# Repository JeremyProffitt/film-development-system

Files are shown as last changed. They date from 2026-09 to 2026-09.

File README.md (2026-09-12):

# film-development-system

Automating black & white and C-41 film processing around a Paterson Super System 4
tank: how to fill and drain it quickly, how to route the chemistry, and a motorised
tumbler that gives the tank real inversion agitation.

Part of a set of analog darkroom projects alongside
[film-dryer](https://github.com/JeremyProffitt/film-dryer) (filtered air system for film drying boxes)
and [film-holders](https://github.com/JeremyProffitt/film-holders).

## Repository layout

```
research/   analysis and drawing sets for the tank itself
tumbler/    the motorised tank tumbler: parametric model, STLs, drawings
```

Every PDF here is generated by the script beside it. Nothing is hand-drawn, and
every dimension quoted on a tumbler sheet is measured off the exported STL rather
than taken from the design intent.

### research/

| file | what it is |
|---|---|
| `tank_drawing_set.py` / `.pdf` | 6 sheets. The Super System 4 range and a dimensioned drawing of every component of the Multi-Reel 3: tank body, centre column, light-trap funnel, lid, agitator rod. |
| `fill_and_drain_study.py` / `.pdf` | 15 sheets. Why the stock tank fills slowly, every route to filling and draining it faster, tilt geometry, pump vs gravity, fluid architecture, carry-over budget, and per-process sequences for B&W and C-41. |

```bash
cd research && python fill_and_drain_study.py
```

### tumbler/

A drum lying on its side with a bore running through it at right angles. The tank
lives in that bore, so one turn of the drum is one full inversion of the tank.
The first 34 mm at each open end carries square grooves on its **inner** wall;
eight TT motors — four per end, 90° apart — sit inside the bore with their wheels
pressing **outward** against those grooves.

| file | what it is |
|---|---|
| `model.py` | parametric model; writes `stl/` |
| `drawings.py` | 4-sheet drawing set; writes `tumbler_drawings.pdf` |
| `doc_framework.py` | shared A3 sheet helpers |
| `render_stl.py` | headless multi-view STL renderer (no OpenGL) |

```bash
cd tumbler && python model.py && python drawings.py
```

Key numbers: drum Ø270 × 198, bore Ø250, tank bore Ø106, 78 grooves at 10.07 mm
pitch, drive ratio 0.252 giving **30 / 47 / 63 inversions per minute** at 3 / 4.5 / 6 V,
about 2.5 N·m at the drum. Every part fits a Bambu H2D with 5 mm clearance per axis.

Bought parts: 8 × [Adafruit 3777](https://www.adafruit.com/product/3777) TT motors,
8 × [Adafruit 3766](https://www.adafruit.com/product/3766) wheels, 6 V 10 A supply.

## Provenance, and what to check before cutting metal

**Paterson publishes no dimensional data for the Super System 4 range.** No spec
sheets, no drawings — this was checked against the manufacturer and six retailers.
The tank dimensions used throughout are a reconstruction built from a small number
of sourced figures:

- internal Ø95 mm (3.75 in), and Multi-Reel 5 internal depths of 229 mm to the
  funnel and 279 mm to the lid — vendor spec Q&A
- retail packaging heights 127 / 165 / 294 / 442 mm for PTP114 / 115 / 117 / 118
- fill volumes 290 ml per 135/126 roll, 370 ml per 127, 500 ml per 120/220

Everything else is derived from a 44 mm reel pitch that reproduces all four
published box heights to within 3 %, or reconstructed proportionally from product
photography. Sheets flag each figure as published, derived or reconstructed.

Before you drill, print or buy fittings: **measure the real tank**. In particular
the tumbler assumes the tank lid rim is larger than Ø106 so the tank cannot pass
through the drum bore, and the groove pitch assumes the 3766 tread block spacing,
which Adafruit does not publish.

## Known weaknesses

Documented on the sheets rather than hidden: eight friction-coupled TT motors will
fight each other at ±10 % speed spread; there are no bearings, so the tyres are the
bearings and are a consumable; the drive is open loop, so the tank parks wherever
it stops; and the drum as modelled needs splitting on the plane containing both
axes to print the cross-bore without support.

## License

Not yet specified.

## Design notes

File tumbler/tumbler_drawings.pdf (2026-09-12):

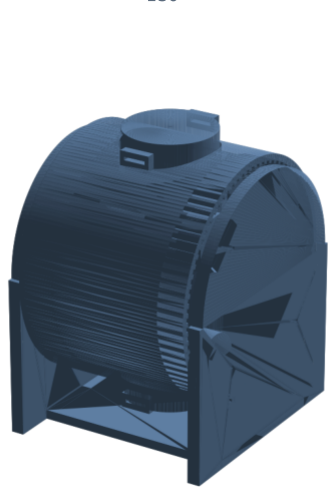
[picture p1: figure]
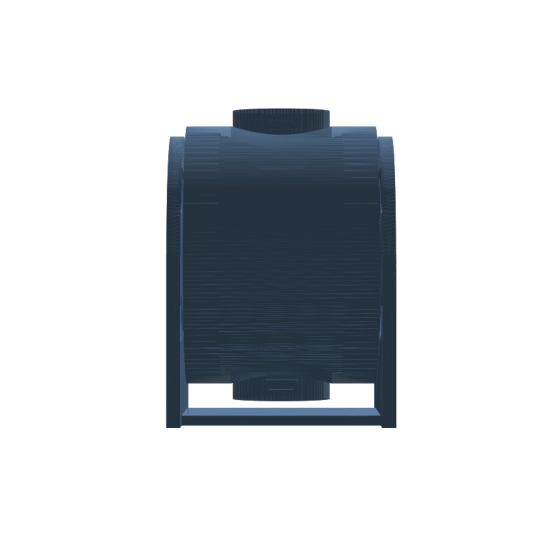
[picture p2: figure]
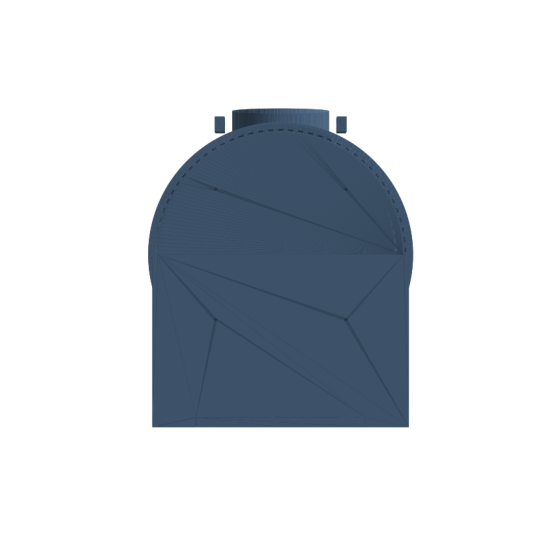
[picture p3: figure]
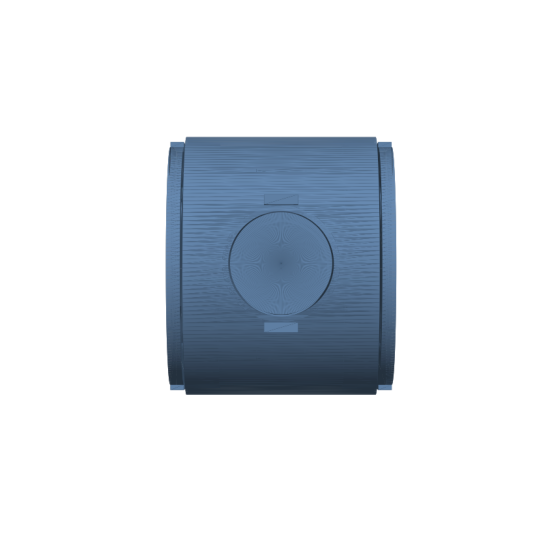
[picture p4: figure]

ISO | FRONT | SIDE | TOP
supply | motor | inversions/min
3.0 V | 120 | 30
4.5 V | 185 | 47
6.0 V | 250 | 63
part | qty | bbox mm | cm³ | filament | fits
assembly | 1 | 232×270×326 | 7630 | 3312 g | —
base | 1 | 232×260×300 | 2282 | 991 g | OK
drum | 1 | 198×270×290 | 1916 | 832 g | OK
motor_mount | 8 | 55×52×27 | 29 | 100 g | OK
PATERSON MULTI-REEL 5 | · | CROSS-AXIS TANK TUMBLER | SHEET 1 OF 4

# Cross-axis tank tumbler — internal drive

eight wheels inside the drum, bearing outward on grooves cut into its bore

Every dimension measured off the exported STL. Motor and wheel data from Adafruit 3777 / 3766. Build envelope Bambu H2D dual-nozzle 300 × 320 × 320 less 5 mm per axis.

## THE PRINCIPLE

A tube lies on its side. A bore runs through it at right angles and the tank lives in that bore, so one turn of the drum is one full inversion of the tank — the motion the

Paterson was designed around.

The first 34 mm at each open end carries square grooves on its INNER wall. FOUR wheels per end sit inside the bore, 90° apart, pressing OUTWARD against those grooves. Eight in all.

## DRIVE

ratio 31.5 / 125 = 0.252
78 grooves at 10.07 mm pitch
8 motors: 4 per end at R93.5, 90° apart stall torque at the drum ≈ 2.5 N·m

## PRINT MANIFEST

total printed material ≈ 1922 g

## FOUR PER END FULLY CONSTRAINS THE DRUM

A wheel inside a bore pushes the drum OUTWARD, so the upper pair carry the weight and the lower pair stop it lifting. Four at 90° trap the drum radially in every direction — a proper four-jaw constraint rather than the

hanging sheave that two would give, and it doubles the driving contacts.

## AXIAL CONSTRAINT

The grooves run axially, so they do not locate the drum along X. The wheel sits in a 34 mm band with
5 mm of end float against the
29 mm tyre — that float is the

constraint. Keep it.

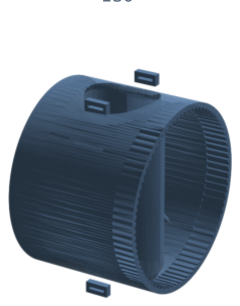
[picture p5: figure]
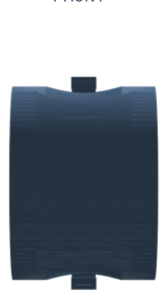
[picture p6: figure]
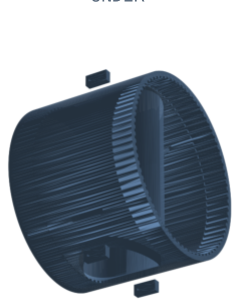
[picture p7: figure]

ISO | FRONT | UNDER
PATERSON MULTI-REEL 5 | · | CROSS-AXIS TANK TUMBLER | SHEET 2 OF 4

# Drum

×1 · a tube with grooves inside both ends

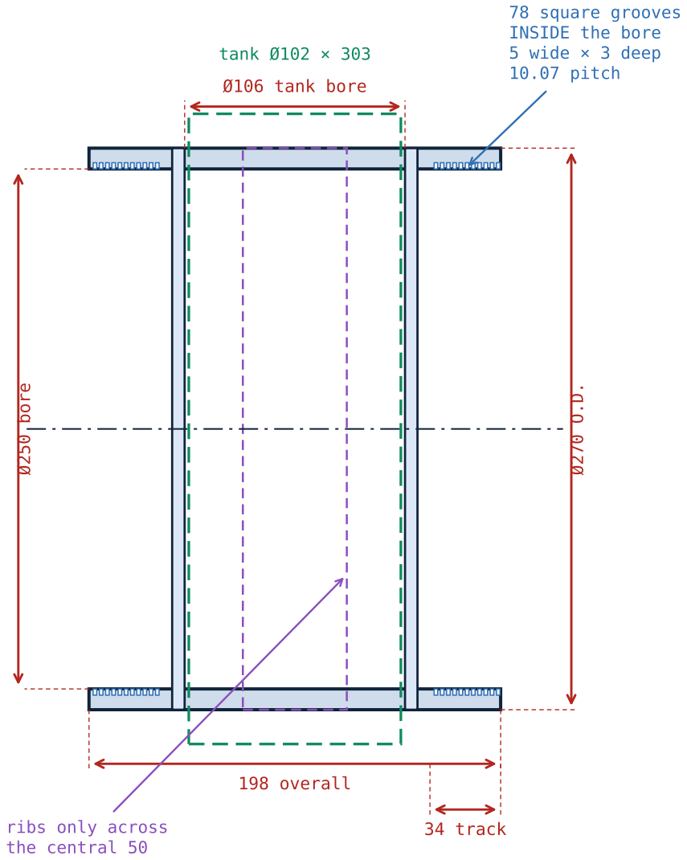
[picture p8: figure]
tank Ø102 × 303; Ø250 bore; 198 overall; 34 track; Ø106 tank bore; 78 square grooves INSIDE the bore 5 wide × 3 deep 10.07 pitch; ribs only across the central 50

### SECTION ON THE BORE AXIS

## CONSTRUCTION

A plain tube, Ø270 outside and Ø250 inside — 10 mm wall.

Grooves cut 3 mm outward from the bore leave 7 mm
of wall at the root.

A Ø118 sleeve carries the tank bore across the tube. Four ribs tie it to the shell, but only across the central 50 mm — everything outboard of that is left clear so the

motor bodies have somewhere to live.

## PRINT IT IN TWO HALVES

On end it is 198 tall and Ø270, which fits — but the

Ø106 cross-bore then prints horizontally and needs support down its whole length.

Split on the plane containing both axes: each half prints flat-face-down support-free, and you lay the tank in rather than threading it through.

## THE GROOVES ARE THE ONE GUESS

10.07 mm pitch assumes the tread block spacing of the 3766 wheel, which Adafruit does not publish. Measure a real tyre before you commit to 78 of them.

If they will not index, a plain high-friction bore works nearly as well — the preload is doing most of the work

either way.

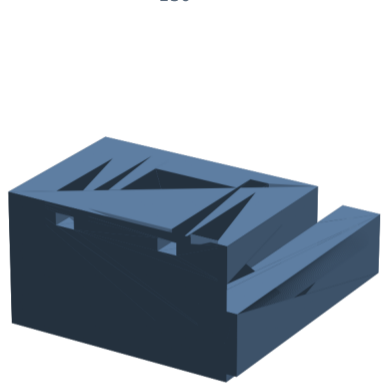
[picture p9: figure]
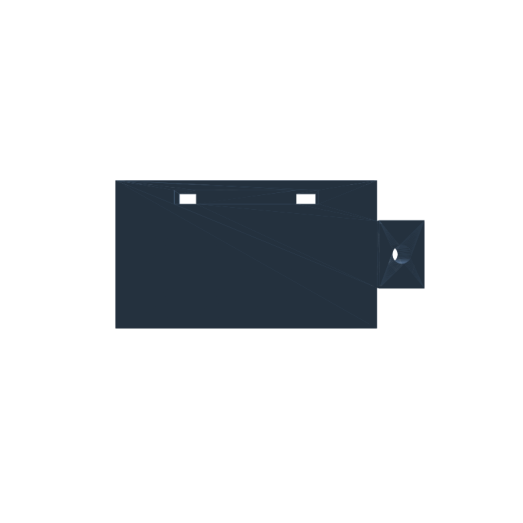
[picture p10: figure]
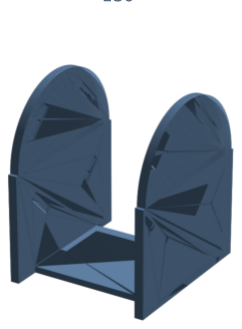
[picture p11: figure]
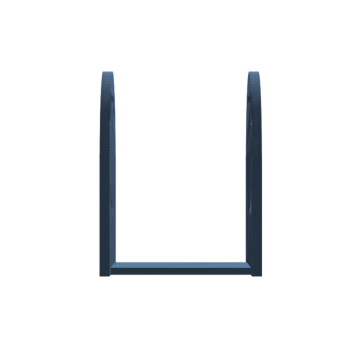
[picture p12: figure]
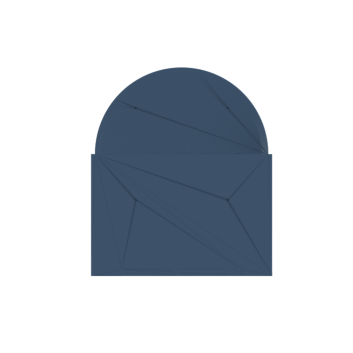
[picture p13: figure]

ISO | FRONT | SIDE
ISO | FRONT

260 foot

175 axis height

half cylinder R124

4 wheels per end
R93.5, 90° apart
PATERSON MULTI-REEL 5 | · | CROSS-AXIS TANK TUMBLER | SHEET 3 OF 4

# Base and motor mount

two uprights, a flat connector, eight mounts

### UPRIGHT — ELEVATION

## BASE

One piece: a flat 10 mm connector between two uprights, each a rectangle with a half cylinder on top. Plates are 14 mm thick and stand 3 mm clear of the drum ends.

Each upright carries FOUR motor mounts on its INBOARD face. Nothing passes through the plate — motor, mount and wheel

are all inside the drum bore.

ASSEMBLY: bolt all eight mounts to the uprights first, then lower the drum straight down over them. The bore is Ø250 and the motor cluster spans Ø206, so it drops in clear.

## THE ONE CONSTRAINT THE BRIEF COULD NOT HAVE

The motor body is 70 mm long and the groove band is only 34 mm deep, so the motor cannot sit wholly within the band. It is mounted gearbox-outward at the drum mouth with the wheel on its inboard shaft, and the body extends a further 70 mm INTO the drum along its axis.

That is why the ribs stop at the central 50 mm. Measured off the mesh, the bore is clear to R125 everywhere the motors live, and the motor envelope reaches R103 — 22 mm of radial clearance to the rotating wall.

part | description | qty | note
Adafruit 3777 | TT gearbox motor | 8 | four per end
Adafruit 3766 | TT wheel Ø63 × 29 | 8 | square tread blocks
M4 × 30 | preload adjuster | 8 | + nuts
M4 × 16 | mount to upright | 16 | + nuts
Zip tie 2.5 mm | motor retention | 16 | two per motor
Webbing strap 25 mm | tank retention | 2 | through the four tabs
PSU + PWM | 6 V 10 A | 1 | 8 motors in parallel

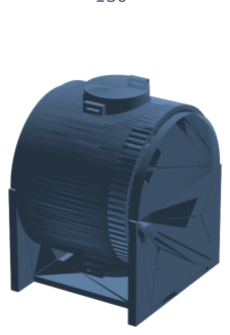
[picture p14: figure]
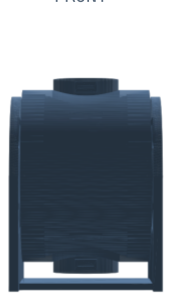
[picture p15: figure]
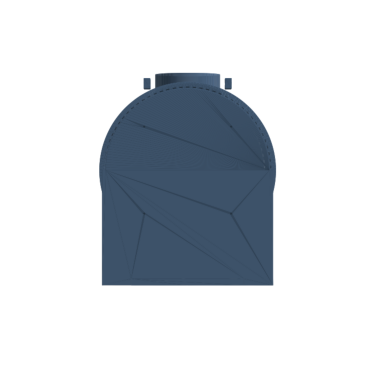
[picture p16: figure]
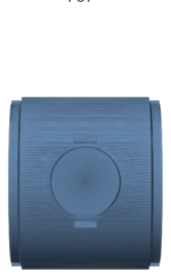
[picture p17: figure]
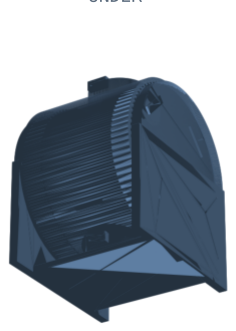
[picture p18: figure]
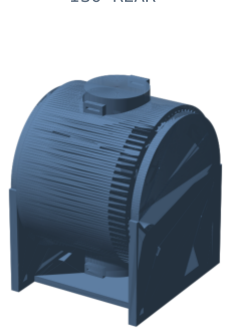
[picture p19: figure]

ISO | FRONT | SIDE | TOP | UNDER | ISO-REAR
PATERSON MULTI-REEL 5 | · | CROSS-AXIS TANK TUMBLER | SHEET 4 OF 4

# Bill of materials and full view set

and what is still wrong with it

BOUGHT PARTS | REMAINING WEAKNESSES

WIRING ROTATES PAST THE MOTORS. Four motors sit inside a rotating tube. Their leads must exit through the open end without fouling the drum — route them along the upright,

not across the mouth.

THE DRUM RUNS ON EIGHT TYRES. No bearings anywhere. Silicone on printed plastic sheds dust and creeps; wheels are a consumable and preload needs re-checking.

EIGHT MOTORS WILL FIGHT EACH OTHER. TT speed spread is about ±10 %, and eight friction-coupled to one drum means the fast ones drive and the slow ones drag. It works, but it costs current and tread life. Stall current is now about 12 A.

OPEN LOOP. No encoder, so the tank parks wherever it stops. Add a microswitch if it must stop upright for filling.

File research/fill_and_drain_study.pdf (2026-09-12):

Route | Fill | Drain | Cuts into
1 Stock pour + invert | 20.0 s | 15.0 s | none
2 Stock + 30° tilt technique | 10.0 s | 15.0 s | none
3 Funnel skirt port 1/2 in | 2.7 s | 15.0 s | funnel
4 Centre-column standpipe | 2.5 s | 9.7 s | column
5 Bottom bulkhead 1/2 in | 2.7 s | 10.3 s | TANK
6 Bottom bulkhead 3/4 in | 1.5 s | 5.9 s | TANK
7 Route 4 or 5 + recirculating pump | as above | as above | as above
8 Motorised tilt cradle | 10.0 s | 12.0 s | none
PATERSON MULTI-REEL 3 (PTP116) | · | FILL & DRAIN STUDY | SHEET 1 OF 15

# Every route, ranked

fill and drain, with and without a bottom port

Hydraulics computed from the PTP116 drawing set. Tank dimensions are a reconstruction — verify with calipers before drilling, printing or buying fittings.

## AND THE ONE THAT SURPRISES PEOPLE

Gravity beats every affordable pump. 0.6 m of head through a 1/2 in line delivers 370 ml/s — 22 litres a minute. A cheap diaphragm pump manages 4–7 L/min; a small peristaltic manages 0.5–3, slower than the stock funnel

you are trying to escape. You would need a 22 L/min chemical-proof pump to

match a shelf 600 mm above the bench.

Pumps are not for filling. They are for recirculating — 4 L/min is ample for continuous agitation — and for pulling the last residue out of the reels.

## ANSWERS TO THE FOUR QUESTIONS

WITH A BOTTOM VALVE
Gravity fill from a raised reservoir, gravity drain to a bucket below the bench. Do not pump either direction. 1/2 in, not 3/4 in. Sheets 9 and 10.

WITHOUT A BOTTOM VALVE
Centre-column standpipe (route 4) if you will print a part; 30° tilt pouring (route 2) if you

will not. Sheets 8 and 4.

PLUMBING IN AND OUT INSIDE THE FUNNEL
Two ways, and they are not equivalent. A port through the funnel SKIRT is a fast top fill and

no drain at all. A tube down the CENTRE COLUMN is a fast bottom fill and a fast drain. Take the second. Sheets 7 and 8.

TILTING
Fill: 25–30° from vertical, and it keeps working

until the tank is 93 % full. Worth about 2×. Drain: the geometry demands 83° to empty and

full inversion to clear the reels. Tilt is a filling tool, not a draining one. Sheets 4–6.

## THE RESULT THAT MATTERS

Route 4 — a printed replacement centre column with an ø18 mm through bore, open at the foot — gives 2.5 s fill and 9.7 s drain. That is

bulkhead performance, from the bottom of the tank, with ZERO holes in the tank. The column is a cheap consumable spare; the tank is not.

If you were going to drill the tank for a 1/2 in port, print a column instead. It is faster, it is reversible, it cannot leak onto your bench, and it is light-tight almost by accident — the feed runs down

a black tube inside a black tube.

chemistry DOWN | air UP

Ø36 throat — shared by
both flows, so it behaves
like a Ø10 orifice

1000 ml
141 mm deep
65.5 | cm² plan | area
PATERSON MULTI-REEL 3 (PTP116) | · | FILL & DRAIN STUDY | SHEET 2 OF 15

# Baseline — why the standard tank is slow

one opening, two fluids, opposite directions

## THE MEASUREMENT EVERYTHING IS ANCHORED TO

A Multi-Reel 3 takes 15–25 s to accept 1000 ml through the funnel. Call it 20 s → 50 ml/s. Back out the

effective orifice:

head in the funnel | h | ≈ 0.05 m
ideal velocity | √(2gh) = 0.99 m/s
with Cd 0.6 | v | = 0.60 m/s
area needed | A = Q/v = 83 mm²
equivalent bore | ø10.3 mm

A Ø36 throat performing like a Ø10 hole. The missing 92 % of the area is occupied by air trying to get out. That is the entire problem, and every route in this document is a different way of giving the air its own
way out.

## COUNTER-CURRENT FLOODING — THE GOVERNING PHYSICS

Liquid down and gas up in one vertical tube is a classic flooding problem. The Wallis criterion,

√j*_g | + | m · √j*_l | = | C
j*_k = j_k · √( ρ_k / (g D Δρ) )

says the tube jams once the two superficial velocities together exceed a constant. Below the limit you get smooth stratified flow; above it, slug flow — the glugging you

can hear. Two levers fall straight out of it:

- raise D | → a bigger path (routes 3–6)
- incline the tube | → gravity separates the phases

instead of making them fight

Everything in this document is one of those two.

## WHEN THIS ACTUALLY MATTERS

Development starts when the first film meets developer, so a 20 s fill means the bottom reel develops 20 s longer than the top one.

at 9 min | 20 s is 3.7 % | invisible
at 6 min | 20 s is 5.6 % | borderline
at 3 min | 20 s is 11 % | a visible density gradient

Below about 4 minutes, no pouring technique is good enough. That threshold should decide whether you build any of this.

### 1 STOCK

in and out fight
over one hole

### 2 TILT 30°

30°

gravity splits the
two flows apart

### 3 SKIRT PORT

fast top fill,
no drain

### 4 STANDPIPE

bottom fill AND
bottom drain,
no holes

### 5 BULKHEAD 1/2

drilled tank

### 6 BULKHEAD 3/4

drilled tank
loses a reel
PATERSON MULTI-REEL 3 (PTP116) | · | FILL & DRAIN STUDY | SHEET 3 OF 15

# The six physical routes

where the liquid goes in, and where the air it displaces comes out

## READING THE MAP

Blue arrows are chemistry, orange arrows are the air it displaces. A route is FAST exactly when the two arrows do not share a hole, and it is EVEN when the blue arrow enters at the bottom, so the liquid front rises through the reels pushing the air ahead of it. Routes 4, 5 and 6 do both. Route 3 separates the flows but still pours onto the top reel. Routes 1 and 2 do neither —

route 2 simply makes the shared hole behave better by tipping it.

## ONLY TWO ROUTES DRAIN FROM THE BOTTOM

Route 4, and routes 5/6. Everything else drains by turning the tank upside down, because the reels leave only ~1.5 mm of radial clearance — no dip tube can run down the wall.

## ROUTE 3 IS A HALF-MEASURE

It buys the full fill speed and none of the drain speed or evenness. Worth it only if you refuse to touch the centre column. Sheet 7.

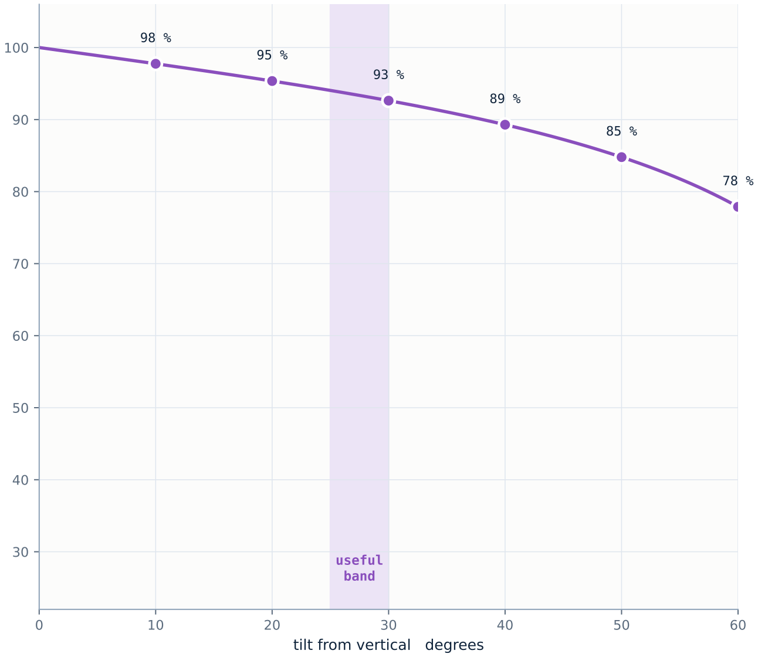
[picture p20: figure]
tilt from vertical degrees; useful band

# fill level when the throat

# floods %

Tilt stays usable almost to the top

0° | glugs | 30° | smooth | 50° | pools in cone
PATERSON MULTI-REEL 3 (PTP116) | · | FILL & DRAIN STUDY | SHEET 4 OF 15

# Tilting to fill — how far, and how far it gets you

the throat floods from the inside only when the tank is nearly full

## WHY TILTING WORKS

Upright, the throat is one vertical pipe carrying liquid down and air up at the same time. The phases fight, the flow goes to slug flow, and it burps.

Tilt it and gravity stratifies them: liquid runs down the low side of the throat, air escapes along the high side. You have made two channels out of one without touching the tank — in flooding terms, you have raised C.

Effect in practice: roughly 20 s → 10 s. About 2×, which matches the 1.5–2.5× that inclining a counter-current

tube is generally worth.

## WHY 25–30° AND NOT MORE

Two limits close in from opposite sides. BELOW ~20° stratification is incomplete and the flow still slugs intermittently. ABOVE ~35° chemistry pools in the funnel cone instead of draining through the throat, and the cone

becomes the restriction instead.

What does NOT stop you is flooding from the inside. With the tank tilted θ the liquid climbs the low wall and

reaches the throat lip when

z_mean | + | r_throat · tanθ | > | 141 mm

At 30° that is 130.6 mm — 93 % full, so you can hold the

tilt through almost the whole pour and only bring the tank upright for the last splash.

## THE TECHNIQUE, WRITTEN OUT

1 Start at 25–30°, throat low-side down, jug spout 20–30 mm clear of the opening — never sealing it.

2 | Pour steadily against the low wall of the cone.
3 | At about 90 % — you will feel it slow — bring the

tank upright and let the last 100 ml settle in. 4 Cap, then start the timer at the HALFWAY point of the pour, not the end. That halves the residual
error for nothing.

Free, reversible, and it works on every tank in the range.

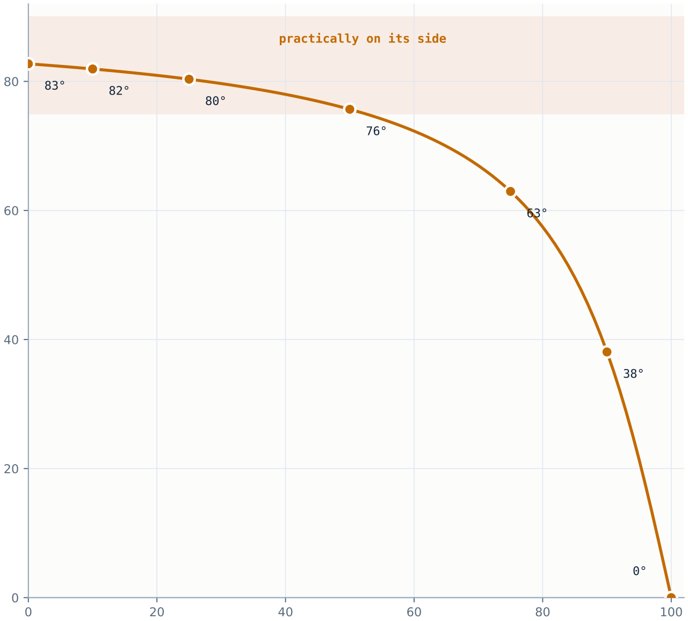
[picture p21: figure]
practically on its; side

liquid remaining in the tank % tilt from vertical needed to keep pouring degrees θ = arctan( (141 − z_mean) / 18 )

PATERSON MULTI-REEL 3 (PTP116) | · | FILL & DRAIN STUDY | SHEET 5 OF 15

# Tilting to drain — the geometry says no

you cannot pour this tank empty without very nearly inverting it

## THE DERIVATION

Tilt the tank by θ. The free surface stays horizontal, so in the tank’s own frame it is a plane inclined at θ and the liquid climbs the low wall by r·tanθ. It can leave

only over the throat lip, 141 mm up the axis and 18 mm out from it, so it pours once the surface covers that lip:

z_mean | + | 18 · tanθ | > | 141
θ > | arctan( (141 − z_mean) / 18 )
full | z=141 | θ = | 0° | spills at once
90 % left | z=127 | θ = 38°
75 % left | z=106 | θ = 63°
50 % left | z= 71 | θ = 76°
25 % left | z= 35 | θ = 80°
bone dry | z= | 0 | θ = 83°

The 18 mm throat radius is the villain. Even if the whole ø95 bore could discharge, the last drop would still need

## arctan(141/47.5) = 71°. AND THE CURVE UNDERSTATES IT

That model is an open cylinder. The real tank adds three things it does not capture:

- the funnel cone is in the way and traps a pocket on

the high side;
- surface tension holds 20–40 ml in the reel spirals at any angle — only a shake clears it;
- air has to come back IN as liquid leaves, so the

counter-current fight from sheet 2 applies in reverse and it glugs the whole way down.

This is why Paterson’s own instruction is to invert. It is not laziness — it is the only angle that works.

## CONCLUSION ON TILT

Tilt is a FILLING tool. It roughly halves the fill time and costs nothing.

It is not a draining tool. Anything short of 80° leaves a quarter of your chemistry in the tank, and a partial tilt that dribbles for 30 s is worse for evenness than a clean 15 s inversion. For a fast drain you need a bottom path —

route 4, 5 or 6.

### FILL

30°

### PROCESS 0° ± inversion

### DRAIN

150°

pivot through the tank axis at its loaded centre of mass → near-zero torque; a hobby servo is enough

PATERSON MULTI-REEL 3 (PTP116) | · | FILL & DRAIN STUDY | SHEET 6 OF 15

# Doing the tilting automatically

a three-position cradle — and why it is really an agitation machine

## SPECIFICATION

PIVOT | through the tank axis at 100 mm up — the loaded

centre of mass. Balanced, so the motor only fights friction.
TORQUE | 1.5 kg at 15 mm worst-case offset ≈ 0.22 N·m.

A 20 kg·cm hobby servo is four times that.
STOPS | 30° fill · 0° process · 150–180° drain.
ROTATION | continuous 180° for inversion agitation, one or
two inversions per 10 s with a dwell at each end.
CRADLE | two printed saddles on ø102, one M6 rod, a strap
over the lid. The lid MUST be strapped — an EVA

cap will let go at 180° under load.
CONTROL | three-position cam, or a servo with three preset
angles and a cheap microcontroller.

## BE HONEST ABOUT WHAT IT BUYS

FILLING | 30° held perfectly still is worth maybe a second over doing it by hand. Not the reason to build it.
DRAINING | A motorised 150° dump genuinely beats hand inversion — repeatable, and it frees both hands. About 12 s, every time.
AGITATION | This is the real prize. An identical inversion pattern every run, every roll, forever. The largest source of run-to-run variation in hand processing is agitation, not fill time.

TEMPERATURE The cradle can sit in a water bath. Add a
| recirculating pump and you have built a Jobo.

## HOW IT COMBINES WITH THE OTHER ROUTES

A tilt cradle and a bottom path are not alternatives — they solve different halves of the problem, and the best machine has both.

cradle alone | 10 s fill · 12 s drain · perfect agitation · no plumbing and no holes
column standpipe alone | 2.5 s fill · 9.7 s drain · hand agitation · one printed part
both | 2.5 s fill · 9.7 s drain · perfect agitation — but the feed hose must release before the cradle inverts,
| which is exactly what the quick-disconnect on sheet 12 is for.

If you build one thing, build the standpipe. If you build two, add the cradle — for the agitation, not for the tilting.

1/2 in barb
through the skirt

throat becomes a
dedicated VENT

diffuser ring spreads
the jet round the wall

liquid level 141 — the port discharges ABOVE it

### FUNNEL SECTION

PATERSON MULTI-REEL 3 (PTP116) | · | FILL & DRAIN STUDY | SHEET 7 OF 15

# Plumbing through the funnel — the skirt port

drill the cheap universal spare, not the tank

## THE IDEA

The funnel and lid are a universal spare — SPTP110, sold

for about the price of a roll of film and fitting every tank in the range. So modify that instead of the tank. Buy two: one stock, one drilled. Swap back in thirty seconds; sell the tank on unmarked.

Fit a 1/2 in barb through the SKIRT — the cylindrical part that seals into the ø95 bore — so it discharges below the

light trap, straight into the tank. The throat above then carries nothing but air.

That is the whole trick: you have not made the hole bigger, you have given the air its own hole. WHAT IT DELIVERS

fill | 2.7 s | identical to a 1/2 in bottom bulkhead
drain | 15 s | unchanged, still by inversion
tank | untouched

The fill figure is real: once the vent is separate, the port is the only restriction left, so it obeys the same gravity equation as any other 1/2 in line.

## THE TWO CATCHES

1 | IT IS STILL A TOP FILL. Chemistry lands on the top reel and works down. You get the speed but not the even rising front a bottom feed gives, and a bare jet will hammer the top film — hence the diffuser ring.
2 | IT DOES NOTHING FOR DRAINING. The reels leave only about 1.5 mm of radial clearance against the bore, so no dip tube can reach the floor down the wall.

A hole in the skirt is a straight line to the film. Trap it exactly like a bulkhead: opaque hose, 300 mm, one 90° bend, and test it per sheet 12.

## VERDICT ON THE SKIRT PORT

Half the benefit for a quarter of the nerve. Take it if you will not modify the centre column and you only care about fill speed — for instance if your problem is a

3-minute push and your drain already overlaps a rinse.

Otherwise go straight to the standpipe on the next sheet. It costs the same effort and does both jobs.

## A NOTE ON VENT SIZING

The vent must pass air at the same volumetric rate the liquid arrives — 370 ml/s at 0.6 m of head. Through the

ø36 throat that is 0.36 m/s of air and a pressure drop well under 1 Pa. Air is a thousand times lighter than developer; venting is never the limit once it has a path of its own. Leave the throat stock.

air out
the throat

feed / drain
hose

radial slots at the foot
feed the whole floor

Ø25 outside / Ø18 bore
wall 3.5
| Standpipe | 1/2 in bulkhead | Winner
fill, 0.6 m head | 2.5 s | 2.7 s | standpipe
drain, free | 9.7 s | 10.3 s | standpipe
holes in the tank | none | one | standpipe
reversible | yes | no | standpipe
light risk | low | medium | standpipe
keeps 3 reels | yes | yes | tie
can still invert | unclip | QD needed | standpipe
PATERSON MULTI-REEL 3 (PTP116) | · | FILL & DRAIN STUDY | SHEET 8 OF 15

# The centre-column standpipe — best route overall

bottom fill and bottom drain, and not one hole in the tank

## WHAT YOU BUILD

One printed part: a replacement centre column whose external geometry matches SPTP116 exactly, so the reels and funnel cannot tell the difference — but with a Ø18 mm

bore running its full length and four radial slots at the foot. The top takes a push-fit hose tail instead of, or as well as, the agitator-rod socket, and a hose drops down through the funnel throat and clips on.

PETG rather than PLA. Four perimeters, no sparse infill in the wall, and soak-test it for a week before it ever sees film — a delaminated column is a light leak.

## WHY IT BEATS DRILLING THE TANK

## THE HYDRAULICS

A Ø18 bore, but a long one — 190 mm of column plus the hose above it — so the discharge coefficient falls from 0.55 to

about 0.45 for pipe friction and two bends.

fill | t = 2.5 s | from 0.6 m of head
drain | t = 9.7 s | free discharge

Even carrying that penalty it still edges a 1/2 in bulkhead, because 18 mm of bore beats 15.8 mm by more than

the friction costs.

Do not go bigger. The column is Ø25 outside and the reels hang on it; a Ø20 bore leaves a 2.5 mm wall that will flex when three loaded reels are pushed down it.

## LIGHT-TIGHTNESS — WHY THIS IS THE SAFER OPTION

The feed path is a black tube inside a black tube inside a light-trapped funnel. Light entering the throat must turn a corner at the hose, travel 190 mm down a matt bore, then turn 90° again at the foot slots before it could reach any film — which is wound on reels facing outward, away from

the column.

Compare a bulkhead: a straight hole through the floor into the chamber the film is sitting in. Both can be made safe. Only one is safe by accident.

## THE ONE REAL RISK

A printed column is structural — the

reels and funnel lock to it. If it cracks mid-process the tank is no longer light-tight. Print two, soak-test both, and keep the stock column.

## OPERATING IT

Fill: clip on, open the clamp, count to three, unclip, cap the column head, agitate as normal.

Drain: clip on, drop the hose end below the bench, let it siphon. No pump, no power.

10.0 | 12.5 | 15.0 | 17.5 | 20.0 | 22.5 | 25.0 | 27.5
bore mm

0

5

10

15

20

25

30

time seconds

4.3 s

16.5 s

3/8"

2.7 s

10.3 s

1/2 in port
routes 3 & 5

2.5 s

9.7 s

standpipe
route 4

1.5 s

5.9 s

3/4 in
route 6

0.9 s

3.6 s

1"

stock funnel
15–25 s

1000 ml · 65.5 cm² plan area · Cd 0.55, and 0.45 for the standpipe

Fill (0.6 m | head)
Drain (free | discharge)
Fill, Cd 0.45 (standpipe)
Drain, Cd 0.45 (standpipe)
PATERSON MULTI-REEL 3 (PTP116) | · | FILL & DRAIN STUDY | SHEET 9 OF 15

# Sizing any bottom path

fill and drain time against bore, with every route marked

## BOTH CURVES GO AS 1/d²

3/8 → 1/2 in | fill 4.3 → 2.7 s | saves 1.6 s
1/2 → 3/4 in | fill 2.7 → 1.5 s | saves 1.2 s
3/4 → 1 in | fill 1.5 → 0.9 s | saves 0.6 s
| | | On filling, 3/4 in buys about a second over 1/2 in — less

than your reaction time on a timer. On draining it is
| | | worth more, 5.9 s against 10.3 s, but sheet 10 shows what

that costs in reels.

## SIZING FROM FIRST PRINCIPLES

Target: fill in under 5 % of the development time.

9 min development | → 27 s allowed
6 min | → 18 s
3 min push | → | 9 s
90 s | E6 first dev | → | 4.5 s

Everything from 3/8 in upward clears the 3-minute bar. Only 1/2 in and above clears the 90-second bar. Since the hydraulic choice is therefore nearly free, make it on mechanical grounds instead — which is sheet 10.

## WHERE THE CURVES STOP HELPING

Below about 2 s the fill is no longer limited by the bore at all. It is limited by how fast you can open a valve, and by the air still leaving through the funnel.

Past ø20 you are engineering for a second you cannot measure. Stop at the standpipe.

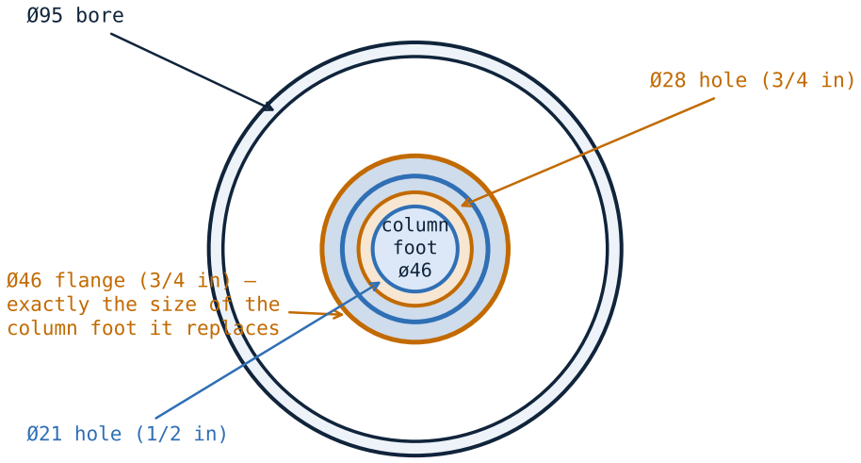
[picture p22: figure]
column foot ø46; Ø28 hole (3/4 in); Ø46 flange (3/4 in) —; exactly the size of the column foot it replaces; Ø21 hole (1/2 in); Ø95 bore

### FLOOR PLAN — CENTRE MOUNTED

reel 1 | 44
reel 2 | 44
reel 3 | 44

### 9 mm — ALL THE SPARE

HEIGHT THERE IS

141 usable depth

### HEIGHT STACK-UP

PATERSON MULTI-REEL 3 (PTP116) | · | FILL & DRAIN STUDY | SHEET 10 OF 15

# If you do drill it — will 3/4 in fit?

the floor plan says yes, the headroom says only just

## 1 THE FLOOR PLAN — PASSES, BUT ONLY AT THE CENTRE

Off-centre is impossible at any size. To clear the ø46
column foot the port centre must sit at r ≥ 38 mm; to keep its flange inside the ø95 bore it must sit at r ≤ 32.5 mm.

No overlap, even for 3/8 in.

Centre mounted, a 3/4 in flange (ø46) sits inside the bore

with 24 mm clearance all round. So the floor is not the constraint — but centring means the column foot has to go

whatever bore you pick, which is most of the work of building a standpipe anyway.

## 2 THE HEADROOM — THIS IS WHAT DECIDES IT

usable depth to the funnel | 141 mm
three reels at 44 mm pitch | 132 mm
——————————————————————————————————
budget for everything inside | 9 mm
1/2 in low-profile nut | 6 mm, legs straddle it
3/4 in low-profile nut | 9–10 mm, they cannot

Exceed 9 mm and the top reel fouls the funnel: the lid will not lock, and a 3-reel tank has quietly become a

2-reel tank.

## VERDICT ON DRILLING

3/4 in is not too wide for the floor — it is too tall for the ceiling. Fitted dead centre it works, fills in 1.5 s, drains in 5.9 s,

and will almost certainly cost you the third reel. If you routinely run two rolls, that is a fair trade.

If you want three rolls and you are set on drilling, fit 1/2 in: 2.7 s and 10.3 s, full capacity.

But note what sheet 8 showed. Both sizes require replacing the column foot, which is the same work as printing a standpipe — and the

standpipe then gives 2.5 s and 9.7 s with no hole at all. The only remaining reason to drill is if you specifically want 3/4 in drain speed and will trade a reel for four seconds.

0.2 | 0.4 | 0.6 | 0.8 | 1.0 | 1.2 | 1.4 | 1.6
reservoir surface above the tank floor m

0

10

20

30

40

delivery litres / minute

3/8 in line

1/2 in line

3/4 in line

Gravity delivery against what pumps in this price class really do

| | 3/8 | in line
| | 1/2 | in line
small peristaltic | 0.5–3 L/min | 3/4 | in line
12 V diaphragm | 4–7 L/min
12 V | centrifugal | 10–30 L/min
PATERSON MULTI-REEL 3 (PTP116) | · | FILL & DRAIN STUDY | SHEET 11 OF 15

# Pump or gravity?

gravity wins on speed; the pump wins at everything it is actually for

## THE HEADLINE

A shelf 600 mm above the bench feeding a 1/2 in line delivers 370 ml/s — 22 litres a minute.

To match that you need a 22 L/min pump that is also fixer-proof. A cheap diaphragm pump gives 4–7; a small peristaltic gives 0.5–3, slower than the stock funnel.

Even 200 mm of head beats every pump here bar a large centrifugal — which is rated at zero head anyway.

## SO USE GRAVITY FOR FILL AND DRAIN

fill | reservoir on a shelf 0.4–0.8 m up, gate clamp
| or ball valve at the tank. No power, no priming, nothing extra to flush.
drain | tank on the bench, waste on the floor. 0.3 m of drop is plenty.

Volume is set by measuring into the reservoir, not by timing a pump — one less thing to get wrong.

## AND USE A PUMP FOR WHAT IT IS GOOD AT

RECIRCULATION one turnover per 15 s is only 4 L/min, and it gives continuous, perfectly repeatable agitation

with no inversion at all. The real reason to own one. LAST RESIDUE gravity leaves 20–40 ml in the spirals; a

peristaltic pulls it out, gravity will not.
NO SHELF | accept 8–15 s instead of 2.5 s.
TEMPERING | circulate through a coil in a water bath.

## CHOOSING A PUMP, IF YOU BUY ONE

PERISTALTIC Only the tube touches chemistry, so compatibility is a tubing question and nothing else. Self-priming, safe to run dry, reverses for fill and drain with one unit, meters volume by revolution count. Slow. Norprene or platinum-cure silicone.
DIAPHRAGM | The practical middle. Demand a Santoprene or EPDM
diaphragm and a polypropylene head. Self-priming, dry-run safe, 4–7 L/min, and cheap.

CENTRIFUGAL Fast and cheap, but not self-priming and destroyed by running dry. Only worth it if it stays flooded.
NEVER | Brass, bronze or aluminium wetted parts — fixer attacks

them and dissolved copper fogs film. Gear pumps. Anything you cannot flush completely between developer and fixer.

## CARRY-OVER — THE HIDDEN COST

Every metre of hose and every pump head holds chemistry the next step inherits. A 1/2 in line 0.5 m long holds 98 ml — a

tenth of your tank volume. Fixer carried into developer is the one that ruins film.

- one dedicated line per chemical, or
- a water flush between every step, or
- quick-disconnects and one hose set

per chemical.

Gravity has the same problem and the same answers, with one fewer wetted part to flush.

If this is you | Build this | Cost | Fill / drain s
Shortest development ≥ 6 min | 2 tilt technique | free | 10 / 15
≥ 4 min, no tools | 2 tilt technique | free | 10 / 15
< 4 min, will print a part | 4 column standpipe | low | 2.5 / 9.7
< 4 min, will not print | 3 funnel skirt port | low | 2.7 / 15
Want the fastest drain | 6 3/4 in bulkhead | med | 1.5 / 5.9
Want repeatability | 8 tilt cradle + 4 | med | 2.5 / 9.7
Want it hands-off | 7 recirc pump + 4 | high | 2.5 / 9.7

floor 7

valve
opaque hose
300 mm,
one 90° bend

diffuser

standoff +
column spigot
≤ 9

BULKHEAD STACK-UP

PATERSON MULTI-REEL 3 (PTP116) | · | FILL & DRAIN STUDY | SHEET 12 OF 15

# Decide, then build

the matrix, the stack-up, and the test you must not skip

## MATERIALS

USE | PP or PVDF bulkheads EPDM or silicone gaskets 316 stainless if metal black EPDM or silicone hose PETG for printed parts
NEVER | brass or bronze — fixer eats it, copper fogs film aluminium — developer eats it natural rubber — swells clear hose of any colour

DO NOT CUT A THREAD IN THE TANK. 7 mm of polystyrene splits on a tapered NPT thread — if not on

assembly then on the third thermal cycle. Through-hole, gasket both sides, nut takes the load.

## DRILLING HIPS

1 | Back the floor with a clamped scrap block.
2 | Step drill, never a hole saw — it grabs and splits.
3 | Low speed, no pressure.
4 | Chamfer both faces 0.5 mm to kill crack initiation.
5 | Nut hand tight plus a quarter turn; HIPS creeps.

## COMMISSIONING, IN ORDER

1 | Water only. Check for leaks at temperature, twice.
2 | Time a 1000 ml fill and a full drain; those numbers
| are now part of your process.
3 | Light-trap test, right. Then one roll of cheap film.

## LIGHT-TRAP TEST — THE ONE YOU MUST NOT SKIP

Any new opening is a light leak until proven otherwise. Light travels in straight lines, so 300 mm of opaque hose with one 90° bend defeats it; a closed valve defeats it absolutely.

1 | Load a strip of the fastest film you use.
2 | Assemble fully, port open, hose connected.
3 | Stand it in the brightest light you have for ten times
your longest process time.
4 | Develop it beside an unexposed control from that roll.
5 | Any density difference at all — the trap has failed.

Lengthen the hose or add a bend. Do not rationalise it.

## THE TRADE-OFF TO SETTLE BEFORE YOU BUILD ANYTHING

A hose attached to the tank cannot be inverted, and inversion is the agitation method the tank was designed around. Three ways out:

Rotary only | Use the agitator rod. Simplest, slightly more prone to edge effects. Re-test your times.
Quick-disconnect | Self-sealing QD at the port. Fill, disconnect, invert exactly as now, reconnect to drain. Keeps every existing time.
Recirculation | Pump continuously through the loop. Most even and most repeatable, and the largest build.

The quick-disconnect is the right first build whichever route you pick: reversible, preserves your development times, costs one fitting.

PATERSON MULTI-REEL 3 (PTP116) | · | FILL & DRAIN STUDY | SHEET 13 OF 15

# Fluid architecture

four sources, one tank, three destinations — and nothing shared that matters

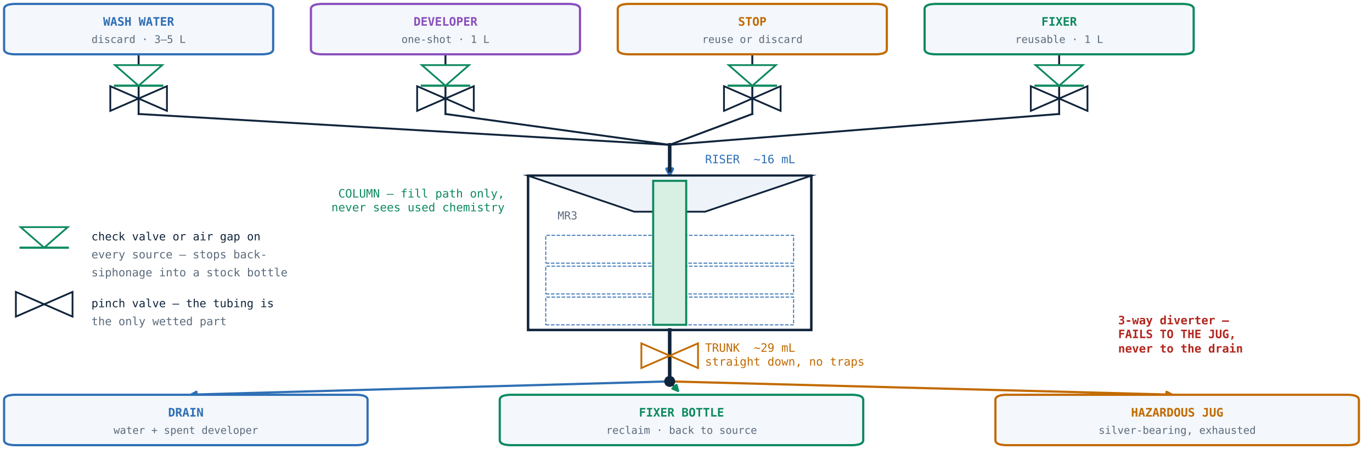
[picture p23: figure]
RISER; COLUMN — fill path only,; never sees used chemistry; TRUNK; straight down, no traps; 3-way diverter — FAILS TO THE JUG, never to the drain; check valve or air gap on every source — stops back-; siphonage into a stock bottle; pinch valve — the tubing is; the only wetted part; WASH WATER; discard · 3–5 L; DEVELOPER; one-shot · 1 L; STOP; reuse or discard; FIXER; reusable · 1 L; DRAIN; water + spent developer; FIXER BOTTLE; reclaim · back to source; HAZARDOUS JUG; silver-bearing, exhausted

## THE TWO RULES THAT DO MOST OF THE WORK

1 | EVERYTHING BELOW THE TANK SLOPES DOWN to its destination. No horizontal runs, no U-traps, no loops. Then every path empties itself after every step and carry-over is a wall film, not a slug. Worth about 40×; sheet 14 does the arithmetic.
2 | ROUTE THE WASH THROUGH THE SHARED PATH. By the end of a wash the trunk has had 3–5 L of water through it. The process you already run IS the flush.

## WHY FILL AND DRAIN ARE SEPARATE PATHS

Fill enters over the top, down the printed column, out at the floor. Drain leaves through a bulkhead in the floor, straight down. They share nothing but the tank.

CORRECTION TO SHEET 8: a standpipe used for BOTH fill and drain has to siphon up over the column head at
190 mm — above the 141 mm liquid surface. It will not

self-prime. It works only if you drain immediately after filling, while the line is still full. For unattended use, drill the floor for the drain or pump the drain leg.

## IF YOU WILL NOT DRILL

Run everything through the column and accept one high point at the column head. Then you need:

- an air-admittance valve at the

apex. It breaks the siphon and lets both legs drain, and it doubles as the back-siphonage guard;
- the drain sequenced straight

after the fill so the line stays primed, or a pump on the drain leg.

Costs one component and some sequencing discipline, and keeps the tank unmarked.

## WHY THIS SHAPE AND NOT A VALVE MATRIX

A full N×M matrix lets any source reach any destination. That sounds flexible and is actually a liability: one stuck valve can put fixer into the developer bottle.

This layout is deliberately poorer. Sources only ever go one way — into the tank.

Destinations are only reachable from the tank. Nothing routes bottle-to-bottle, so no single failure can cross-contaminate a stock solution. The worst case is a ruined run, not a ruined litre.

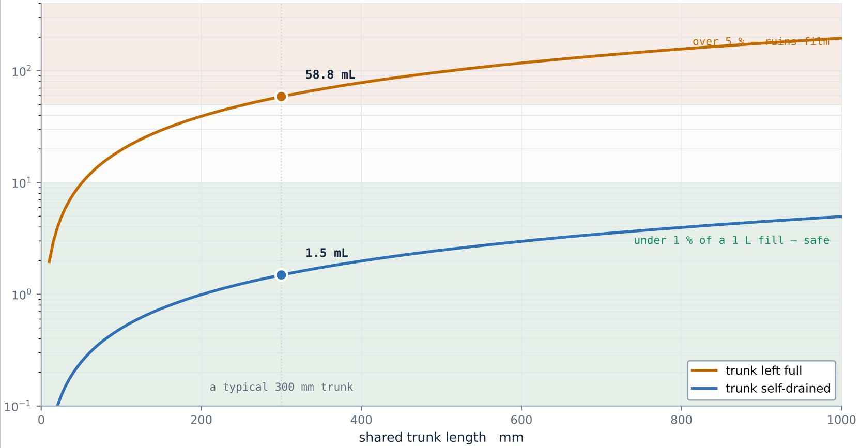
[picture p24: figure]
shared trunk length mm; under 1; % of a 1 L fill — safe; over 5 % — ruins film; a typical 300 mm trunk; trunk self-drained; trunk left full

carried into the next step mL (log)

½ in bore · 0.1 mm drained film · 40× apart at every length

path element | left full mL | self-drained mL
Column Ø18 × 190 | 48.3 | 1.1
Trunk ½ in × 300 | 58.8 | 1.5
Valve bodies | ~5 | ~0.2
TOTAL | 112 | 2.8
as % of a 1 L fill | 11.2 % | 0.28 %
PATERSON MULTI-REEL 3 (PTP116) | · | FILL & DRAIN STUDY | SHEET 14 OF 15

# Carry-over budget

the one number that decides whether any of this works

## THE COMPONENT BUDGET

## AND THE PURGE IT IMPLIES

To flush a residue down to 1 mL of the old liquid, a
well-mixed line needs | V = V_res · ln( V_res / 1 mL ):
left full | 112 mL | → purge 528 mL
self-drained | 2.8 mL | → purge 2.9 mL

Half a litre per step, or three millilitres. That ratio is the whole argument for fixing the geometry first.

## THE TWO WAYS CARRY-OVER HURTS — THEY ARE NOT THE SAME

POISONING Fixer into developer. A few mL per litre is enough to depress contrast and cause dichroic fog. Cumulative and irreversible. This is the one that scraps film.

DILUTION Wash water into developer. 112 mL of water in a 1 L fill is an 11 % dilution — an 11 % change in development

activity, which reads as flat, thin negatives. Predictable, repeatable, and completely avoidable.

Self-draining geometry fixes both at once. Where it cannot — the developer always follows the wash — a purge to waste is the

answer, and at 3 mL it is not worth automating around.

## WHERE 0.1 mm COMES FROM

A low-viscosity aqueous solution draining off a vertical plastic wall leaves a film of roughly 0.05–0.15 mm. 0.1 mm is the

middle of that band.

It scales with the square root of viscosity, so cold, syrupy stock leaves more and warm working-strength solution leaves less.

Call the self-drained figure 2–5 mL

rather than 2.8 mL and nothing changes: still forty times better than leaving the line full, still under half a percent of the tank volume.

# | Step | Liquid | Class | Vol | Source | Destination | Purge first?

1 | Pre-soak (optional) | water | discard | 1 L | wash line | drain | no
2 | Developer | one-shot | discard | 1 L | dev reservoir | drain | YES ~150 mL
3 | Stop | water or acid | either | 1 L | wash / stop bottle | drain / stop bottle | no
4 | Fixer | reusable | reclaim | 1 L | fixer bottle | fixer bottle | no
5 | Wash | water | discard | 3–5 L | wash line | drain | no — this IS the flush
6 | Wetting agent | one-shot | discard | 1 L | small reservoir | drain | no
# | Step | Liquid | Class | Vol | Source | Destination | Purge first?

1 | Pre-warm | water 38 °C | discard | 1 L | tempered wash | drain | no
2 | Colour developer | replenished | reclaim | 1 L | dev bottle | dev bottle | YES → replenisher
3 | Bleach | reusable | reclaim | 1 L | bleach bottle | bleach bottle | no
4 | Wash | water | discard | 2 L | wash line | drain | no
5 | Fixer | reusable | reclaim | 1 L | fixer bottle | fixer bottle | no
6 | Wash | water | discard | 3 L | wash line | drain | no
7 | Stabiliser | reusable | reclaim | 1 L | stab bottle | stab bottle | no
PATERSON MULTI-REEL 3 (PTP116) | · | FILL & DRAIN STUDY | SHEET 15 OF 15

# Process sequences

who follows whom, and the one step that needs a purge

## BLACK & WHITE — one-shot developer, reusable fixer

## C-41 — every bath reusable, 38 °C, and it breaks the easy rule

## THE FREE WIN — CONTAMINATION ONLY MATTERS ONE WAY

In both sequences each bath is preceded by something harmless to it:

stop ← developer | neutralised anyway
fixer ← stop | acid into acid fixer
wash ← fixer | irrelevant
developer ← wash | DILUTION — the only harmful one

So exactly one step needs a purge, and in B&W it is the one-shot, where 150 mL to waste costs pennies.

## WHERE C-41 IS HARDER

The colour developer is reusable AND follows a wash, so its purge cannot go to waste without losing stock. Send it to the replenisher jug and replenish on volume.

Bleach carried back into the developer is the serious one — it oxidises the developing agent. Never sequence

bleach before developer, and if a blix replaces steps 3 and 5, put a wash either side of it.

All lines and bottles must hold 38 °C ± 0.3.

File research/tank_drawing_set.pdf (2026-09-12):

Model | Code | slots Reel | 35 mm | 120/ 220 | Chemistry full load | Overall height * | Retail box height | Column part
35 mm Tank | PTP114 | 1 | 1 | — | 290 ml | 127 mm | 127 mm (P) | SPTP114
Universal | PTP115 | 2 | 2 | 1 | 580 ml | 171 mm | 165 mm (P) | SPTP115
Multi-Reel 3 | PTP116 | 3 | 3 | 2 | 1000 ml | 215 mm | ~210 mm * | SPTP116
Multi-Reel 5 | PTP117 | 5 | 5 | 3 | 1500 ml | 303 mm | 294 mm (P) | SPTP117
Multi-Reel 8 | PTP118 | 8 | 8 | 5 | 2500 ml | 435 mm | 442 mm (P) | SPTP118

## CURRENT SUPER SYSTEM 4 TANK RANGE

Five tanks for sale — five different heights, one diameter.

## SHEET INDEX

2 | Tank body | | PTP116 | model-specific
3 | Centre column | | SPTP116 | model-specific
4 | Light-trap funnel | | SPTP110 | fits ALL SS4 tanks
5 | Lid / EVA watertight cap | . . . . | SPTP110 | fits ALL SS4 tanks
6 | Agitator rod (stirrer) | | | SPTP109 | fits ALL SS4 tanks

Only the tank barrel and the centre column change length with
reel count. Because each column is cut to its model's length, its head always sits directly under the funnel — which is why one

short agitator rod serves the whole range, from 35 mm to MR8.

## PROVENANCE — READ FIRST

Paterson publishes NO dimensional drawings or spec sheets for the Super System 4 range. Checked: patersonphotographic.com, macodirect, Parallax, B&C Camera, Unique Photo, Adorama, EMS Diasum. None list a height or a diameter.

(P) THE ONLY HARD NUMBERS
- internal ø 95 mm (3.75 in)
- Multi-Reel 5 internal depth 229 mm (9 in) to the

funnel, 279 mm (11 in) to the lid [B&H spec Q&A]
- box heights 127 / 165 / 294 / 442 mm for

PTP114 / 115 / 117 / 118 [Amazon item details]
- fill volumes 290 ml per 135/126 roll, 370 ml per

127, 500 ml per 120/220 [Paterson / macodirect]
- funnel+lid kit SPTP110 fits all SS4 tanks; column +agitator kits are per-model SPTP114–118; agitator

rod SPTP109 is stated to fit 35 mm through MR8 [Freestyle 142007, Firstcall PATE902, KHB PTS109]

( * ) DERIVED
Reel pitch 44 mm = 229 mm ÷ 5 reels. Every barrel height then follows as N × 44 + 83 mm, which lands within 3 % of all four published box heights.
(R) RECONSTRUCTED
Column, funnel, cap and rod carry no published dimension of any kind. Their shapes are taken from product photography and scaled off the ø95 bore. Treat every (R) number as ±5 %.

DO NOT cut a water jacket, fixture or replacement part to these figures without checking the real tank with calipers first.

PATERSON SUPER SYSTEM 4 | · | MULTI-REEL 3 TANK SET | SHEET 1 OF 6
Provenance: | (P) published / vendor-stated | ( * ) derived from (P) data | (R) reconstructed from product photography — shape correct, number estimated
TITLE | RANGE SUMMARY
PART No. | —
FITS | Super System 4
UNITS | millimetres
SCALE | n/a
STATUS | reconstruction — verify before machining

200

250

SECTION A-A; 199* overall barrel; 7R base 13R collar; TANK BODY — PTP116; HEIGHT RULE; (derived); barrel height; overall + lid; PTP114; (box 127 P); PTP115; (box 165 P); PTP116; (box ~210 *); PTP117; (box 294 P); PTP118; (box 442 P); PATERSON SUPER SYSTEM 4; MULTI-REEL 3 TANK SET; SHEET 2 OF 6; TITLE; TANK BODY; PART No.; FITS; Multi-Reel 3; UNITS; millimetres; SCALE; 1:2 approx

One-piece high-impact polystyrene moulding.

BORE IS COMMON TO THE WHOLE RANGE
Ø102 outside / Ø95 inside on every Super
System 4 tank, 35 mm through Multi-Reel 8.
Only the barrel length changes.

wall 3.5* | | funnel seats here — fill line | 3 × bayonet lug, 120° apart | (R)

where N = number of 35 mm reel slots.

192* internal depth to lid

141* internal depth to funnel

CAPACITY, PTP116
6 × 4×5 in sheets in a MOD54 holder

reel envelope 3 × | 44

A 120 reel occupies ~70 mm of column, so
roll-film capacity is always lower than
35 mm capacity in the same barrel.

Ø95 P PLAN | — TOP

The bayonet collar detail at the rim is (R) —
lug count and angle are read off photographs.

200

250

190* column length; bore; drive tangs —; the; over these; Part; Tank; Reels; Length *; SPTP114; 35 mm Tank; SPTP115; Universal; SPTP116; Multi-Reel 3; SPTP117; Multi-Reel 5; SPTP118; Multi-Reel 8; CENTRE COLUMN — SPTP116; DERIVED LENGTH BY MODEL; PATERSON SUPER SYSTEM 4; MULTI-REEL 3 TANK SET; SHEET 3 OF 6; TITLE; CENTRE COLUMN; PART No.; FITS; Multi-Reel 3 only; UNITS; millimetres; SCALE; 1:2 approx

MODEL-SPECIFIC. Paterson sells a separate column
+ agitator kit for each tank, which is the clearest
evidence that this is the only part besides the
barrel whose length changes:

agitator rod slots

4R flange ¹⁴R head | | reel 3

Reels push down over the column and are keyed to
it; the head sits just clear of the funnel so the
agitator rod can engage it through the throat.

reel 2

reel 1

Every dimension on this sheet is (R) except the
length, which is (*) — it follows the same 44 mm
reel pitch that reproduces all four published
tank box heights. Wall thickness, flange and
head geometry are read off product photographs.

Ø46R | foot flange

SECTION — COLUMN ON CENTRELINE

−150 | −100 | −50 | 0 | 50 | 100 | 150 | 200 | 250
| | | | mm

−50

0

50

100 | chemistry in — light-trapped annulus

58R overall

6R rim 6R throat wall

| | Ø110R rim flange

bayonet lug (R)

| Ø36R | | throat | PLAN — TOP
| SECTION
Ø94R | seals | in Ø95 bore

## LIGHT-TRAP FUNNEL — SPTP110

UNIVERSAL PART. Freestyle sells this as the “Super System 4 Tank Top Lid & Funnel Replacement Kit”, #142007 / Paterson SPTP110, described as fitting all Super System 4 series tanks — so one

funnel covers 35 mm through Multi-Reel 8. (P)

FUNCTION
Drops over the centre column and twists clockwise onto the bayonet collar. The annular gap between the cone and the throat is the light trap: liquid passes, light does not. The tank is daylight-safe the moment it clicks home.

The one-piece large-diameter lid and funnel is the feature Paterson actually advertises — it is what

makes the tank fill and empty fast. (P)

DEPTH INSIDE THE BARREL
The funnel intrudes 51 mm into the tank. That is the one funnel dimension with real evidence behind it: the Multi-Reel 5 measures 279 mm internal to the lid but only 229 mm to the funnel. (P)
279 − 229 = 50.8 mm.

All other numbers on this sheet are (R), scaled off the known Ø95 bore that the skirt seals into.

PATERSON SUPER SYSTEM 4 | · | MULTI-REEL 3 TANK SET | SHEET 4 OF 6
TITLE | LIGHT-TRAP FUNNEL
PART No. | SPTP110 (pt 1)
FITS | ALL Super System 4
UNITS | millimetres
SCALE | 1:1.5 approx

SECTION; PLAN — TOP; 17R overall; 14R skirt; over skirt; Ø92R sealing bead; the funnel rim (R); internal bead grips; grip ribs (R); what makes inversion agitation possible.; TWO AGITATION MODES; Cap fitted; → invert the whole tank.; the funnel throat and twist (rotary).; of both, may be used.; WHY IT MATTERS DIMENSIONALLY; others.; the funnel rim it has to seal against.

−150 | −100 | −50 | 0 | 50 | 100 | 150 | 200 | 250
| | | | mm

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
## LID / WATERTIGHT CAP — SPTP110

UNIVERSAL PART, supplied in the same replacement kit as the funnel (Freestyle #142007, Paterson SPTP110, “fits all Super System 4 series tanks”). (P)

MATERIAL
Flexible EVA. It is a friction cap, not a screw thread — it stretches over the funnel rim and is
2 | Cap removed | → drop the agitator rod through

Paterson's own copy says either, or a combination

Because the funnel is common to the whole range, so is this cap — every Super System 4 tank, from

the 127 mm 35 mm tank to the 442 mm Multi-Reel 8, closes with the identical Ø98 mm cap. It is the reason a spare lid bought for one tank fits the

All dimensions on this sheet are (R), scaled from

PATERSON SUPER SYSTEM 4 | · | MULTI-REEL 3 TANK SET | SHEET 5 OF 6
TITLE | LID / WATERTIGHT CAP
PART No. | SPTP110 (pt 2)
FITS | ALL Super System 4
UNITS | millimetres
SCALE | 1:1 approx

ELEVATION 1:1; DETAIL B — ENGAGEMENT; END; 115R overall length; 16R tip 7R knob; knob; shaft; slot; 10R slot depth; slots straddle the column drive tangs

−100 | −50 | 0 | 50 | 100 | 150 | 200
| | | mm

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
## AGITATOR ROD — SPTP109

UNIVERSAL PART. The dealer copy is explicit:
“The slots in the bottom of the rod engage with the

tangs in the reel core of all Super System tanks from 35 mm to Multi-Reel 8.”

[KHB Photografix PTS109 / Paterson SPTP109] (P)

WHY ONE SHORT ROD FITS EVERY TANK
This looks wrong at first — a Multi-Reel 8 is

3.4× the height of a 35 mm tank. It works because the CENTRE COLUMN is the part cut to length, not the rod. Whatever the tank, the column head ends just below the funnel throat, so the rod only ever has to span the funnel — about 115 mm.

That is also why Paterson sells the column and the agitator together as a per-model kit, while the rod alone has a single part number.

USE
Rotary agitation only. Remove the cap, drop the rod through the throat, twist. Inversion uses the cap instead and needs no rod.

Freestyle also list a short “swizzle stick” for

single and double reel tanks, so a second, shorter variant is in circulation. Treat the 115 mm here as the multi-reel length.

Every dimension on this sheet is (R).

PATERSON SUPER SYSTEM 4 | · | MULTI-REEL 3 TANK SET | SHEET 6 OF 6
TITLE | AGITATOR ROD (STIRRER)
PART No. | SPTP109
FITS | ALL Super System 4
UNITS | millimetres
SCALE | 1:1 / detail 3:1

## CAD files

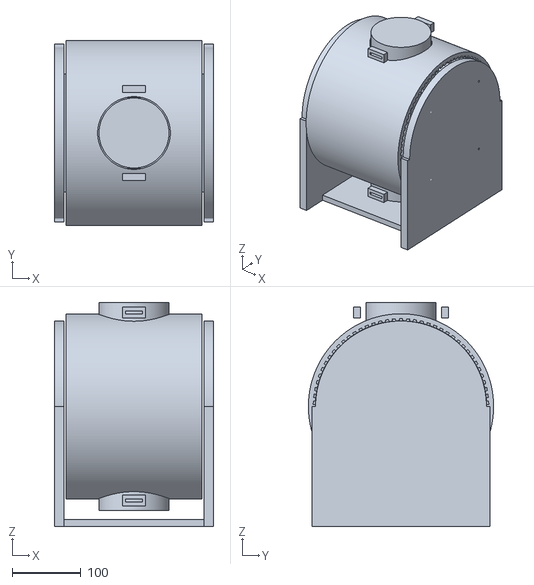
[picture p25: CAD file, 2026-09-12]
tumbler/stl/assembly.stl
232.0 x 270.0 x 326.5

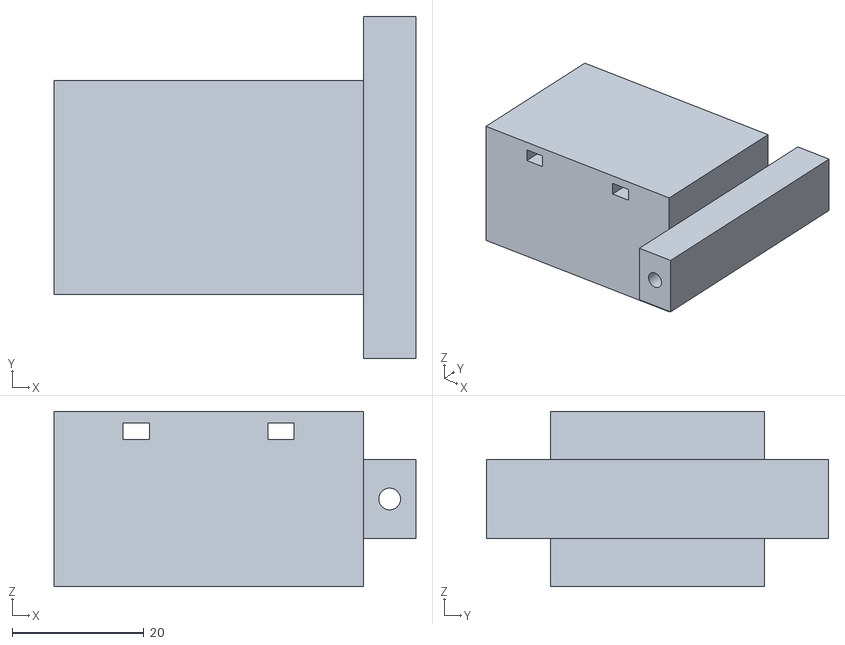
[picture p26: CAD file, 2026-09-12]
tumbler/stl/motor_mount.stl
55.0 x 52.0 x 26.6

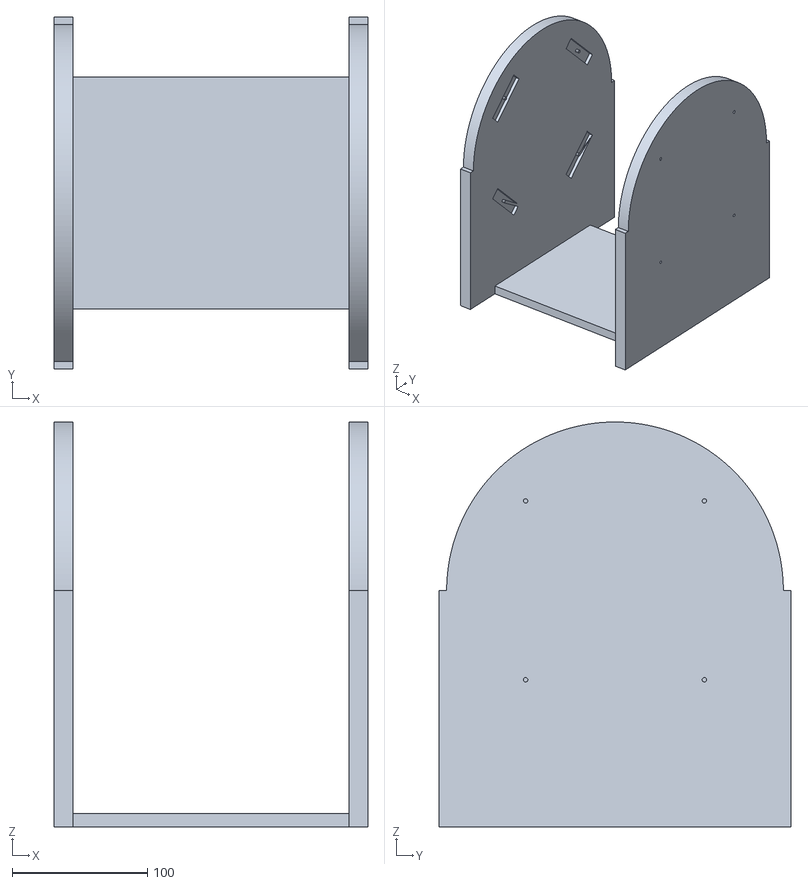
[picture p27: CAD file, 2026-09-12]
tumbler/stl/base.stl
232.0 x 260.0 x 299.5

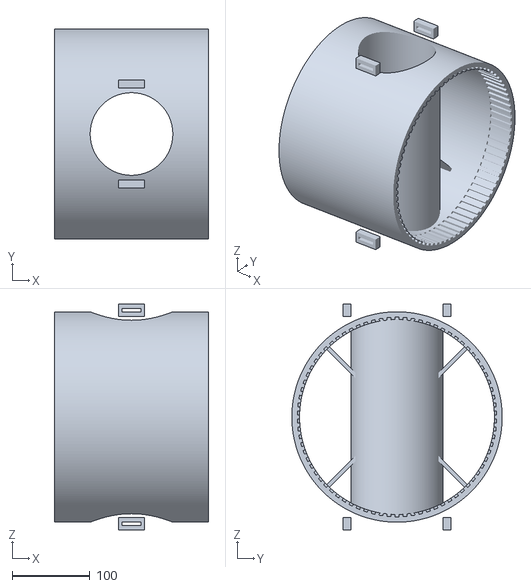
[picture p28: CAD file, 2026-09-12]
tumbler/stl/drum.stl
198.0 x 270.0 x 290.0
